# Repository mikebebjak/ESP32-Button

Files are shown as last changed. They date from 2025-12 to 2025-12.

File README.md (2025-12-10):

# ESP32-Button
ESP32 with a single button for one action and 0 current draw when not in use



I wanted to create a simple ESP32 PCB whose sole job was to send a single command over the Internet and then go completely dormant. Basically, the PCB, which is powered by 2x AA batteries, consumes 0 current when dormant (so not deep sleep) the button activates the power circuit to turn the ESP32 to run whatever code you want and then it shuts itself off.
The power design utilizes an boost circuit with an Enable pin that is pulled high by the button and then a GPIO on the ESP is used to keep it high until code execution is finished.

The use case I wanted it for was a simple Timesheet update for starting and finishing freelance work. The Google Sheets script is attached as well for those interested in this use case.

To use the Apps Script, simply create a Google Sheet with a sheet named Log and then add an App script and copy the contents of the txt file into it. Then give it permissions and deploy. You will need the URL to paste into the codes.h header so the ESP knows where to send it.

Note that this is not the most secure thing to be running with data of any sensitivity so please DYOR.

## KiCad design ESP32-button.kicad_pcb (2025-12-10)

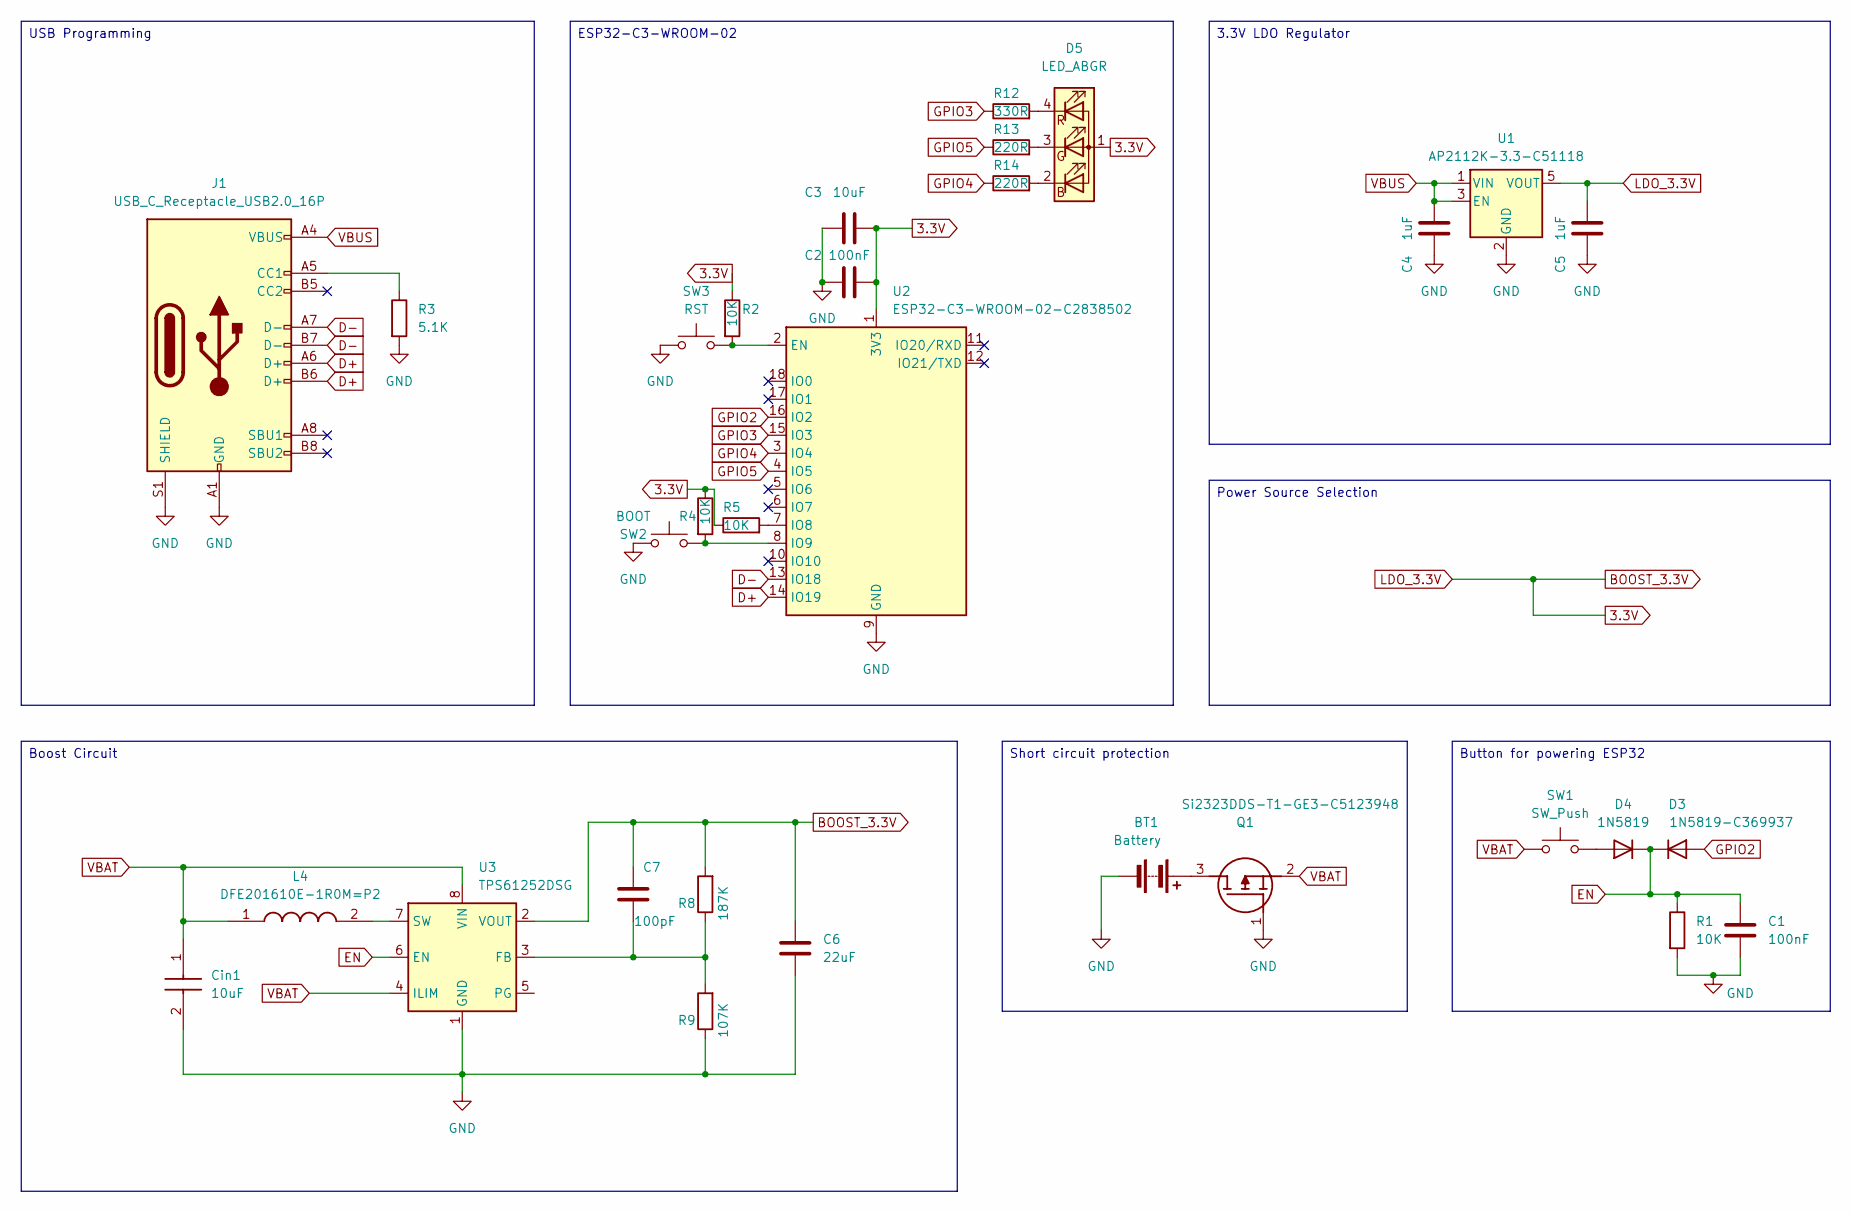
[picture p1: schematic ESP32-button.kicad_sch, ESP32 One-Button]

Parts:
BT1: Battery; BAT_BH2AAAPC
C1, C2: 100nF; C_0402_1005Metric
C3: 10uF; C_0805_2012Metric_Pad1.18x1.45mm_HandSolder
C4, C5: 1uF; C_0402_1005Metric
C6: 22uF; C_1210_3225Metric
C7: 100pF; C_0402_1005Metric
Cin1: 10uF; C_0805_2012Metric; Mouser Part Number 81-GRJ155R60J106ME1D
D3: 1N5819-C369937; D_SOD-323F
D4: 1N5819; D_SOD-323F
D5: LED_ABGR; TJ-S1615SW6TGLCCYRGB-A5
J1: USB_C_Receptacle_USB2.0_16P; USB_C_Receptacle_G-Switch_GT-USB-7010ASV
L4: DFE201610E-1R0M=P2; L_0805_2012Metric; Mouser Part Number 81-DFE201610E-1R0MP2
Q1: Si2323DDS-T1-GE3-C5123948; SOT-23-3; Mouser Part Number 78-SI2323DDS-T1-GE3
R1, R2, R4, R5: 10K; R_0402_1005Metric
R3: 5.1K; R_0603_1608Metric
R8: 187K; R_0402_1005Metric
R9: 107K; R_0402_1005Metric
R12: 330R; R_0402_1005Metric
R13, R14: 220R; R_0402_1005Metric
SW1: SW_Push; SW_TS04-66-50-BK-100-SMT
SW2: BOOT; SW_SPST_CK_KXT3
SW3: RST; SW_SPST_CK_KXT3
U1: AP2112K-3.3-C51118; SOT-23-5
U2: ESP32-C3-WROOM-02-C2838502; ESP32-C3-WROOM-02
U3: TPS61252DSG; WSON-8-1EP_2x2mm_P0.5mm_EP0.9x1.6mm

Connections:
3.3V: C2.2, C3.1, C5.2, C6.1, C7.1, D5.1 (A), R2.1, R4.1, R5.1, R8.2, U1.5 (VOUT), U2.1 (3V3), U3.2 (VOUT)
D+: J1.A6 (D+), J1.B6 (D+), U2.14 (IO19)
D-: J1.A7 (D-), J1.B7 (D-), U2.13 (IO18)
EN: C1.1, D3.1 (K), D4.1 (K), R1.1, U3.6 (EN)
GND: BT1.2 (-), C1.2, C2.1, C3.2, C4.1, C5.1, C6.2, Cin1.2, J1.A1 (GND), J1.A12 (GND), J1.B1 (GND), J1.B12 (GND), J1.S1 (SHIELD), Q1.1 (G), R1.2, R3.2, R9.1, SW2.1, SW3.1, U1.2 (GND), U2.9 (GND), U2.19 (GND), U3.1 (GND), U3.9 (GND)
GPIO2: D3.2 (A), U2.16 (IO2)
GPIO3: R12.1, U2.15 (IO3)
GPIO4: R14.1, U2.3 (IO4)
GPIO5: R13.1, U2.4 (IO5)
unnamed: BT1.1 (+), Q1.3 (D)
unnamed: D4.2 (A), SW1.2
unnamed: D5.2 (BK), R14.2
unnamed: D5.3 (GK), R13.2
unnamed: D5.4 (RK), R12.2
unnamed: J1.A5 (CC1), R3.1
unnamed: R2.2, SW3.2, U2.2 (EN)
unnamed: R5.2, U2.7 (IO8)
unnamed: R4.2, SW2.2, U2.8 (IO9)
unnamed: C7.2, R8.1, R9.2, U3.3 (FB)
unnamed: L4.2, U3.7 (SW)
VBAT: Cin1.1, L4.1, Q1.2 (S), SW1.1, U3.4 (ILIM), U3.8 (VIN)
VBUS: C4.2, J1.A4 (VBUS), J1.A9 (VBUS), J1.B4 (VBUS), J1.B9 (VBUS), U1.1 (VIN), U1.3 (EN)

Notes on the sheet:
3.3V LDO Regulator
Button for powering ESP32
USB Programming
Boost Circuit
Short circuit protection
Power Source Selection
ESP32-C3-WROOM-02

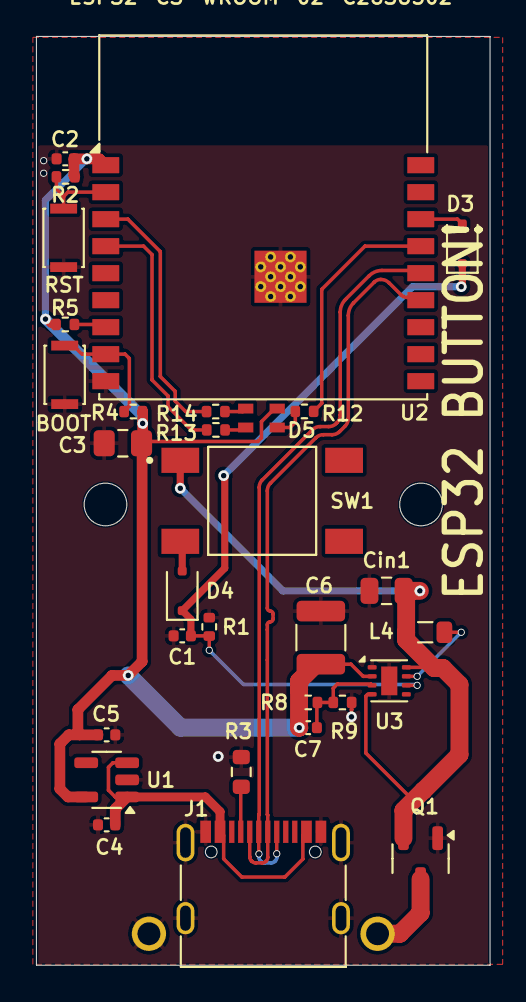
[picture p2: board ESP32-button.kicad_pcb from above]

Board: 2 copper layers, 25.2 x 51.6 mm, 31 parts (1 on the bottom side), 22 nets.

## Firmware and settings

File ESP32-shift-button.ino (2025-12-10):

#include <WiFi.h>
#include <HTTPClient.h>
#include "codes.h"

#define PWR_EN 2  // GPIO2 to keep the ESP32 powered on when the button isn't held
#define LED_R 3
#define LED_G 5
#define LED_B 4

int connectToWiFi() {
  for (int i = 0; i < wifi_network_count; i++) 
  {
    WiFi.begin(wifi_ssids[i], wifi_passwords[i]);
    int retries = 0;

    while (WiFi.status() != WL_CONNECTED && retries++ < 10) {
      delay(500);
    }
    if (WiFi.status() == WL_CONNECTED) 
      return 1;
  }
  return 0;
}

int sendToSheet() {
  if (WiFi.status() == WL_CONNECTED)
  {
    HTTPClient http;
    http.begin(scriptURL); //scriptURL from your codes.h header
    http.addHeader("Content-Type", "application/json");
    int httpCode = http.POST("{}");  // Send (mostly) empty POST to run the Google Sheets script
    http.end();
    return httpCode;
  }
}

void setup() {
  pinMode(PWR_EN, OUTPUT);
  digitalWrite(PWR_EN, HIGH);
  delay(500);

  pinMode(LED_R, OUTPUT);
  pinMode(LED_G, OUTPUT);
  pinMode(LED_B, OUTPUT);

  analogWrite(LED_R, 100);
  digitalWrite(LED_B, HIGH);
  digitalWrite(LED_G, HIGH);

  int code = 7;
  Serial0.begin(115200);
  Serial0.println("Connecting...");
  
  bool connected = connectToWiFi();

  if(connected)
  {
    digitalWrite(LED_B, LOW);
    delay(500);
    digitalWrite(LED_B, HIGH);

    Serial0.println("Connected. Sending POST...");
    code = sendToSheet();
    Serial0.println(code);

    if(code == 200)
      Serial0.println("Success!");
    else
      Serial0.println("POST failed");
  }
  else
  {
    Serial0.println("Failed to connect to Wifi");
  }

  WiFi.disconnect(true);
  
  digitalWrite(LED_G, LOW);
  delay(1000);
  digitalWrite(LED_G, HIGH);

  digitalWrite(PWR_EN, LOW);
}

void loop() {
  // unused
}
